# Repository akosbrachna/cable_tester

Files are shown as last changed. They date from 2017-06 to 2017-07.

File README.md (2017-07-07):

# cable_tester

Simple cable tester for checking CAT network cables. It can check wiring issues as well as cable length.

Wiring mismatch testing is based on voltage division.

Cable length measurement is based on signal reflection.

The microcontroller is a PIC18F45k50. This model is used because it has a CTMU unit that enables the 
microcontroller to measure nanosecond short times which is required for cable length measurement. 
The C program was written in MPLAB IDE.

The SMD circuit was designed in Eagle CAD circuit designer. The PCB is double-layered.
Future plan is to add another comparator and make cable length measurement on all 4 pairs.

Master circuit schematic:

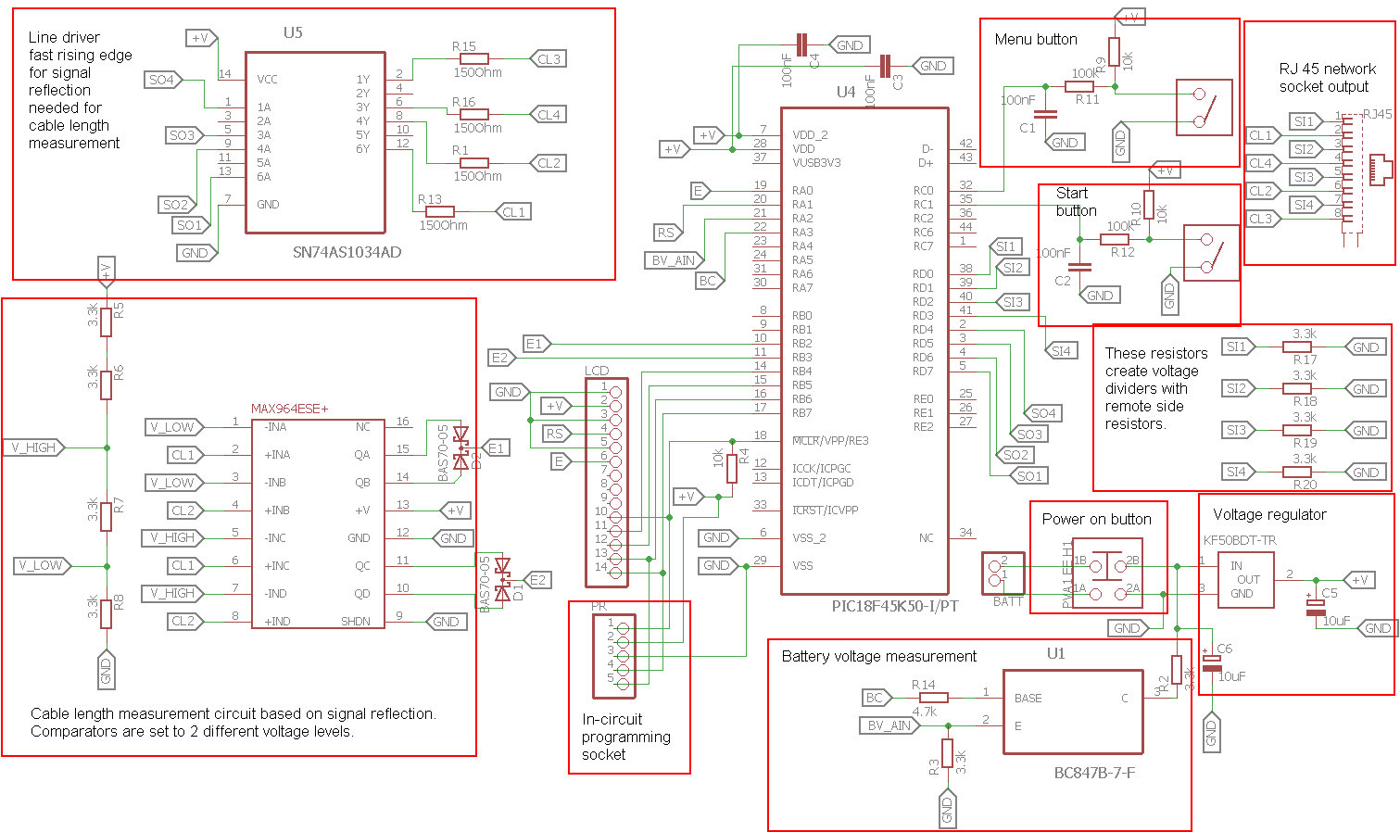
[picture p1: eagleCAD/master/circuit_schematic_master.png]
Circuit schematic


Remote circuit schematic:

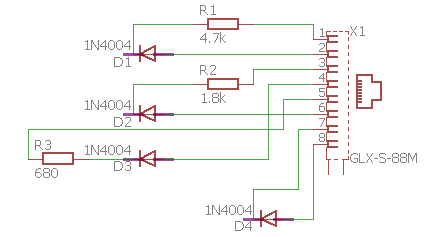
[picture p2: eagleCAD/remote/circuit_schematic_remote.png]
Circuit schematic


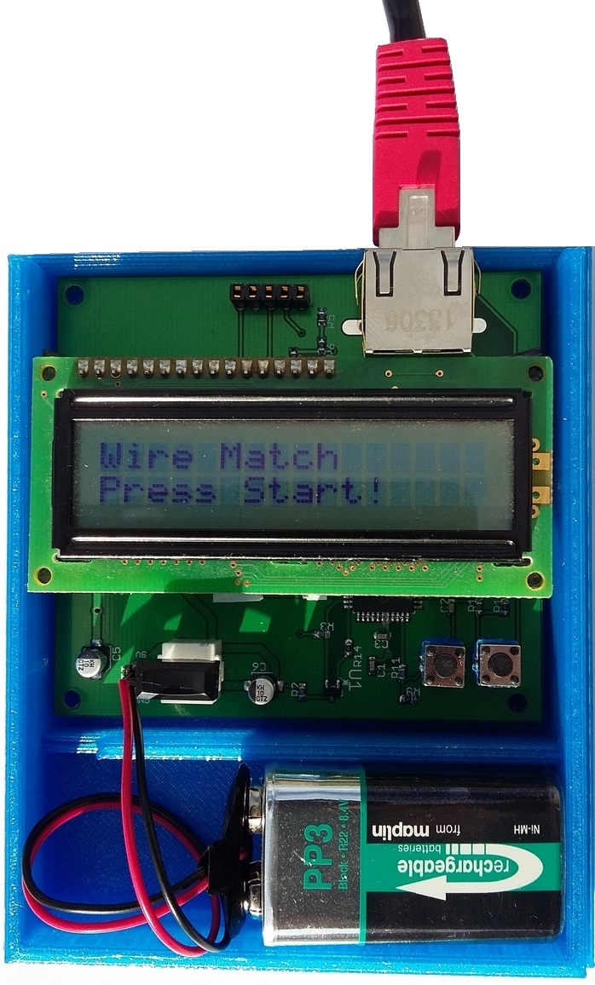
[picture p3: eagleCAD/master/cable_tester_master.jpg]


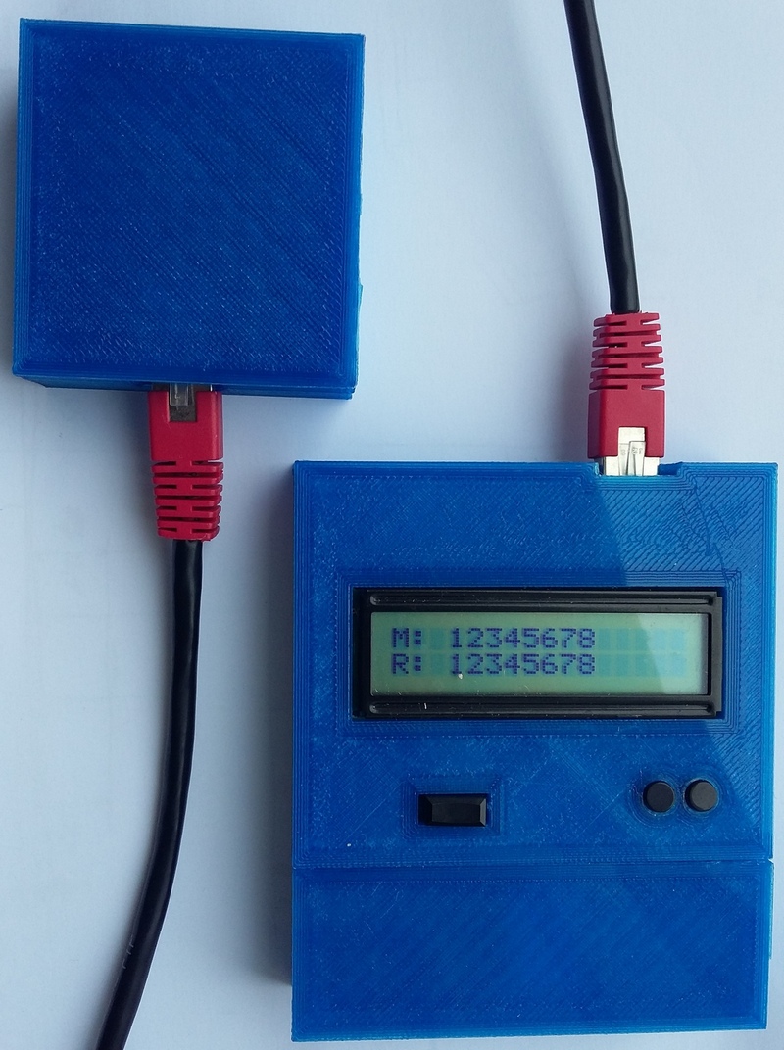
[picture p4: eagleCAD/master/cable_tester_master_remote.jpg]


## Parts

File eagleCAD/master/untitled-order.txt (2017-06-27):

Order list for C:/Users/Setup/Documents/eagle/cable_tester_rx_mod/untitled.sch
Exported from EAGLE with DesignLink

Quantity	Value	Package	Order code	Manufacturer	Manuf. Code	Availability	Price (from)	Description
1		1X02	unknown					
4	100nF	C0603	432210	YAGEO (PHYCOMP)	CC0603KRX7R7BB104	139457	0.0080	YAGEO (PHYCOMP) - CC0603KRX7R7BB104 - CAP, MLCC, X7R, 100NF, 16V, 0603
2	10uF	153CLV-0405	2346364	RUBYCON	16TZV10M4X6.1	972	0.0821	RUBYCON - 16TZV10M4X6.1 - CAP, ALU ELEC, 10UF, 16V, SMD
2	BAS70-05	SOT23	2463435	ON SEMICONDUCTOR	BAV74LT1G	12326	0.026	ON SEMICONDUCTOR - BAV74LT1G - DIODE, SWITCHING, 50V, SOT-23
1		1X14	unknown					
1		1X05	unknown					
4	150Ohm	R0603	1527376	TE CONNECTIVITY / NEOHM	CPF0603F150RC1	551	0.0213	TE CONNECTIVITY / NEOHM - CPF0603F150RC1 - RES, THIN FILM, 150R, 1%, 0.063W, 0603
10	3.3k	R0603	2332009	TE CONNECTIVITY	CRGH0603F3K3	6429	0.0106	TE CONNECTIVITY - CRGH0603F3K3 - RES, THICK FILM, 3K3, 1%, 0.2W, 0603
3	10k	R0603	1652827	VISHAY	CRCW060310K0FKTA	144	0.0158	VISHAY - CRCW060310K0FKTA - RES, THICK FILM, 10K, 1%, 0.1W, 0603
2	100k	R0603	2331753	TE CONNECTIVITY	CRGH0603J100K	7643	0.0084	TE CONNECTIVITY - CRGH0603J100K - RES, THICK FILM, 100K, 5%, 0.2W, 0603
1	4.7k	R0603	1469807	VISHAY	CRCW06034K70FKEA	-2	0.0052	VISHAY - CRCW06034K70FKEA - RES, THICK FILM, 4K7, 1%, 0.1W, 0603
1	1-406541-6	RJ45	2310179	AMP - TE CONNECTIVITY	1-406541-6	2278	1.5	AMP - TE CONNECTIVITY - 1-406541-6 - MODULAR, JACK, RJ45, THT, 8P8C
1		TO252	1467757	STMICROELECTRONICS	KF50BDT-TR	530	0.363	STMICROELECTRONICS - KF50BDT-TR - IC, V REG, LDO 5V, SMD
1	MAX964ESE+	SO16	2518928	MAXIM INTEGRATED PRODUCTS	MAX964ESE+	11	9.74	MAXIM INTEGRATED PRODUCTS - MAX964ESE+ - IC, COMPARATOR, HIGH SPEED,  QUAD
1	PVA1_EE_H1	PVA1_EE_H1	2435325	C & K COMPONENTS	PVA1 EE H1 3.5N V2	1899	0.753	C & K COMPONENTS - PVA1 EE H1 3.5N V2 - SWITCH PUSH DPST
2	FSM4JRT	FSM4JRT	2396052	TE CONNECTIVITY / ALCOSWITCH	FSM4JRT	12410	0.0617	TE CONNECTIVITY / ALCOSWITCH - FSM4JRT - SWITCH, TACTILE, 50MA, 24VDC, THT
1	BC847B-7-F	SOT95P240X110-3N	1773608	DIODES INC.	BC847B-7-F	-2	0.014	DIODES INC. - BC847B-7-F - TRANSISTOR, NPN, SOT23
1	PIC18F45K50-I/PT	TQFP80P1200X1200X120-44N	2305837	MICROCHIP	PIC18F45K50-I/PT	720	2.13	MICROCHIP - PIC18F45K50-I/PT - MCU, 8BIT, PIC18, 48MHZ, TQFP-44
1	SN74AS1034AD	SOIC127P600X175-14N	1470728	TEXAS INSTRUMENTS	SN74AS1034AD	87	1.26	TEXAS INSTRUMENTS - SN74AS1034AD - IC, BUFFER/DRIVER/RECEIVER, SMD

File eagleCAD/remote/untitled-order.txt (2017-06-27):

Order list for C:/Users/Setup/Documents/eagle/cable_tester_remote/untitled.sch
Exported from EAGLE with DesignLink

Quantity	Value	Package	Order code	Manufacturer	Manuf. Code	Availability	Price (from)	Description
4	1N4004	DO41-10	2335181	VISHAY	1N4004-E3/54	23574	0.0307	VISHAY - 1N4004-E3/54 - RECTIFIER, STANDARD, 1A, 400V, DO-204AL
1	4.7k	0309/12	1126988	MULTICOMP	MCMF0W4FF4701A50	856	0.0284	MULTICOMP - MCMF0W4FF4701A50 - METAL FILM RESISTOR, 4.7KOHM, 250mW, 1%
1	1.8k	0309/12	1129139	MULTICOMP	MCMF0W4FF1801A50	3541	0.0284	MULTICOMP - MCMF0W4FF1801A50 - METAL FILM RESISTOR, 1.8KOHM, 250mW, 1%
1	680	0309/12	9340823	MULTICOMP	MF50 680R	13028	0.0158	MULTICOMP - MF50 680R - RESISTOR, 0.5W 1% 680R
1	GLX-S-88M	GLX-S-88M	unknown

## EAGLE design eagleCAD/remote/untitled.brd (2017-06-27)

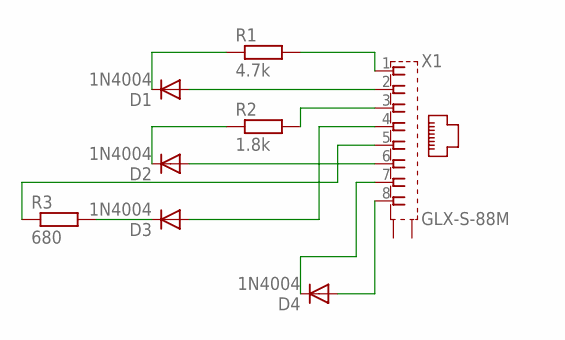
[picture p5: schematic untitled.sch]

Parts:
D1, D2, D3, D4: 1N4004; DO41-10; MPN 1N4004-E3/54
R1: 4.7k; 0309/12; MPN MCMF0W4FF4701A50
R2: 1.8k; 0309/12; MPN MCMF0W4FF1801A50
R3: 680; 0309/12; MPN MF50 680R
X1: GLX-S-88M

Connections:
unnamed: D1.A, X1.2
unnamed: D1.C, R1.1
unnamed: R1.2, X1.1
unnamed: D2.A, X1.6
unnamed: D2.C, R2.1
unnamed: R2.2, X1.3
unnamed: D3.A, X1.4
unnamed: D3.C, R3.2
unnamed: R3.1, X1.5
unnamed: D4.A, X1.8
unnamed: D4.C, X1.7

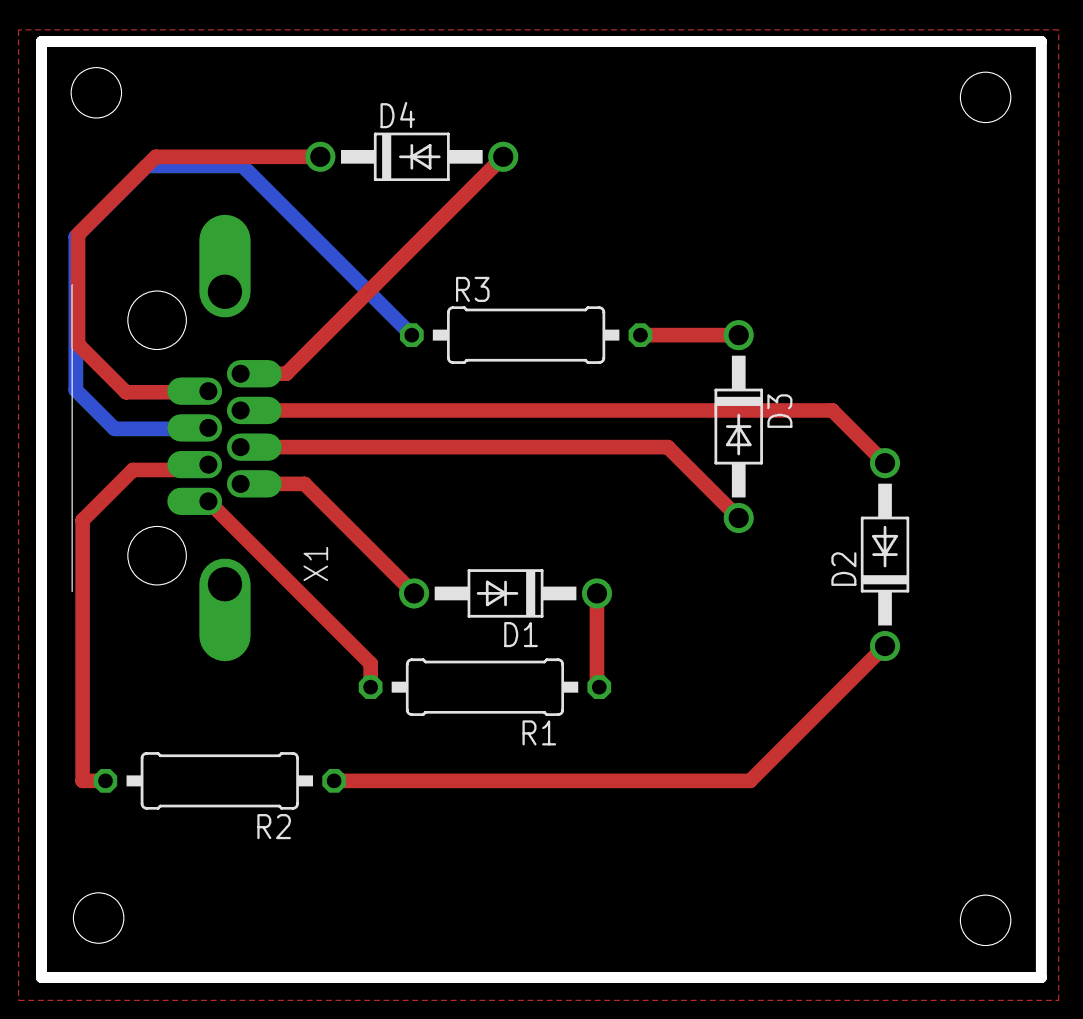
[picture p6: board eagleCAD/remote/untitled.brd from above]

Board: 2 copper layers, 55.5 x 52.0 mm, 8 parts (0 on the bottom side), 11 nets.

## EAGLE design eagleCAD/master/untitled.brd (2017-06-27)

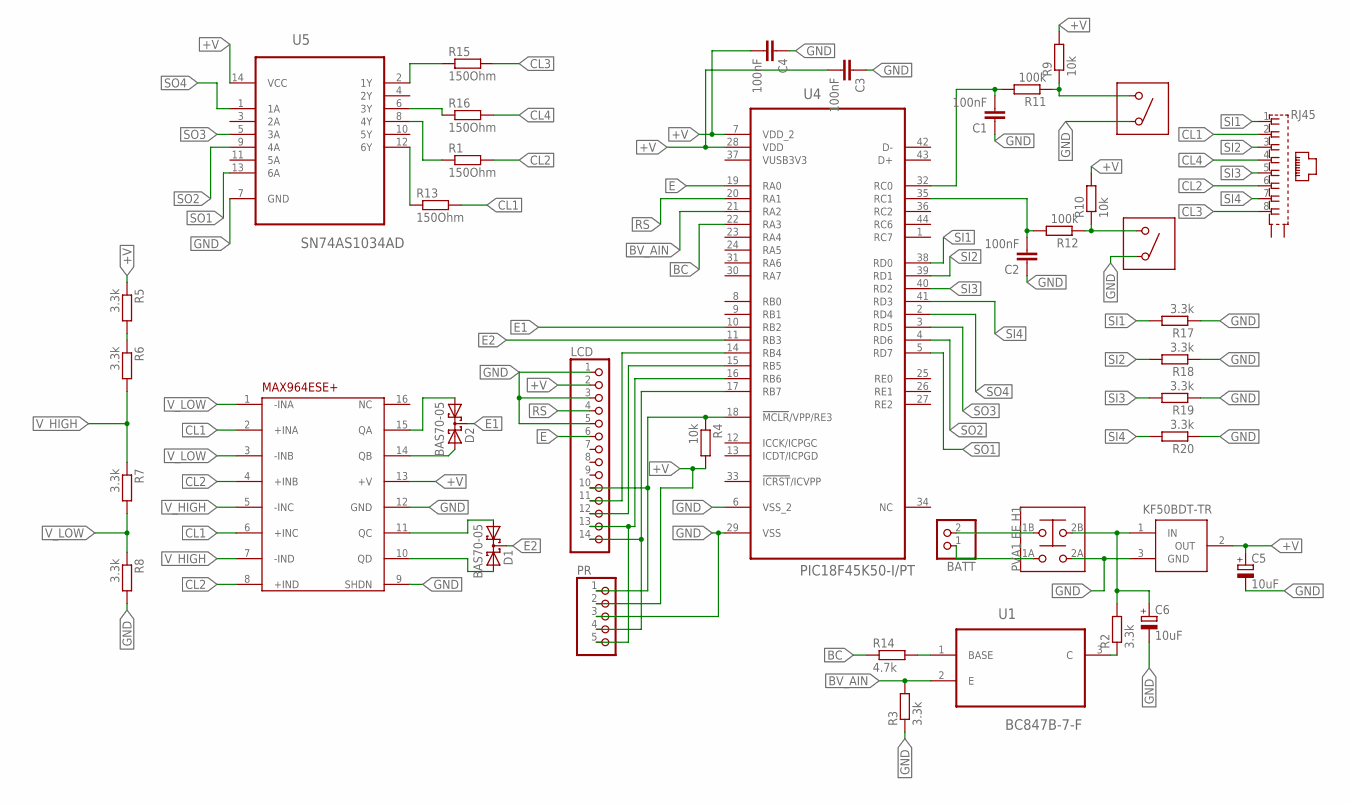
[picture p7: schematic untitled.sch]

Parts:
BATT: PINHD-1X2; 1X02
C1, C2, C3, C4: 100nF; C0603; MPN CC0603KRX7R7BB104
C5, C6: 10uF; 153CLV-0405; MPN 16TZV10M4X6.1
D1, D2: BAS70-05; SOT23
LCD: PINHD-1X14; 1X14
PR: PINHD-1X5; 1X05
R1, R13, R15, R16: 150Ohm; R0603; MPN CPF0603F150RC1
R2, R3, R5, R6, R7, R8, R17, R18, R19, R20: 3.3k; R0603; MPN CRGH0603F3K3
R4, R9, R10: 10k; R0603; MPN CRCW060310K0FKTA
R11, R12: 100k; R0603; MPN CRGH0603J100K
R14: 4.7k; R0603; MPN CRCW06034K70FKEA
RJ45: 1-406541-6; RJ45
U1: BC847B-7-F; SOT95P240X110-3N
U4: PIC18F45K50-I/PT; TQFP80P1200X1200X120-44N
U5: SN74AS1034AD; SOIC127P600X175-14N
U$1: KF50BDT-TR; TO252
U$2: MAX964ESE+; SO16; MPN MAX964ESE+
U$3: PVA1_EE_H1
U$4, U$5: FSM4JRT; MPN FSM4JRT

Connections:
+V: C3.2, C4.2, C5.+, LCD.2, PR.2, R4.2, R5.1, R9.2, R10.2, U4.7 (VDD_2), U4.28 (VDD), U5.14 (VCC), U$1.2 (OUT), U$2.13 (+V)
BC: R14.1, U4.22 (RA3)
BV_AIN: R3.2, U1.2 (E), U4.21 (RA2)
CL1: R13.2, RJ45.2, U$2.2 (+INA), U$2.6 (+INC)
CL2: R1.2, RJ45.6, U$2.4 (+INB), U$2.8 (+IND)
CL3: R15.2, RJ45.8
CL4: R16.2, RJ45.4
E: LCD.6, U4.19 (RA0)
E1: D2.3 (C), U4.10 (RB2)
E2: D1.3 (C), U4.11 (RB3)
GND: C1.1, C2.1, C3.1, C4.1, C5.-, C6.-, LCD.1, LCD.3, LCD.5, PR.3, R3.1, R8.2, R17.1, R18.1, R19.1, R20.1, U4.6 (VSS_2), U4.29 (VSS), U5.7 (GND), U$1.3 (GND), U$2.9 (SHDN), U$2.12 (GND), U$3.2A, U$4.2, U$5.2
MCLR: LCD.10, PR.1, R4.1, U4.18 (!MCLR!/VPP/RE3)
unnamed: LCD.11, U4.14 (RB4)
unnamed: LCD.12, U4.15 (RB5)
unnamed: R14.2, U1.1 (BASE)
unnamed: R2.1, U1.3 (C)
unnamed: R1.1, U5.8 (4Y)
unnamed: R13.1, U5.12 (6Y)
unnamed: R16.1, U5.6 (3Y)
unnamed: LCD.13, PR.5, U4.16 (RB6)
unnamed: C1.2, R11.2, U4.32 (RC0)
unnamed: BATT.2, U$3.1B
unnamed: R15.1, U5.2 (1Y)
unnamed: BATT.1, U$3.1A
unnamed: LCD.14, PR.4, U4.17 (RB7)
unnamed: D2.1 (A1), U$2.15 (QA)
unnamed: R5.2, R6.1
unnamed: D2.2 (A2), U$2.14 (QB)
unnamed: D1.1 (A1), U$2.11 (QC)
unnamed: R9.1, R11.1, U$4.1
unnamed: D1.2 (A2), U$2.10 (QD)
unnamed: C2.2, R12.2, U4.35 (RC1)
unnamed: R10.1, R12.1, U$5.1
unnamed: C6.+, R2.2, U$1.1 (IN), U$3.2B
RS: LCD.4, U4.20 (RA1)
SI1: R17.2, RJ45.1, U4.38 (RD0)
SI2: R18.2, RJ45.3, U4.39 (RD1)
SI3: R19.2, RJ45.5, U4.40 (RD2)
SI4: R20.2, RJ45.7, U4.41 (RD3)
SO1: U4.5 (RD7), U5.13 (6A)
SO2: U4.4 (RD6), U5.9 (4A)
SO3: U4.3 (RD5), U5.5 (3A)
SO4: U4.2 (RD4), U5.1 (1A)
VUSB3V3: U4.37 (VUSB3V3)
V_HIGH: R6.2, R7.1, U$2.5 (-INC), U$2.7 (-IND)
V_LOW: R7.2, R8.1, U$2.1 (-INA), U$2.3 (-INB)

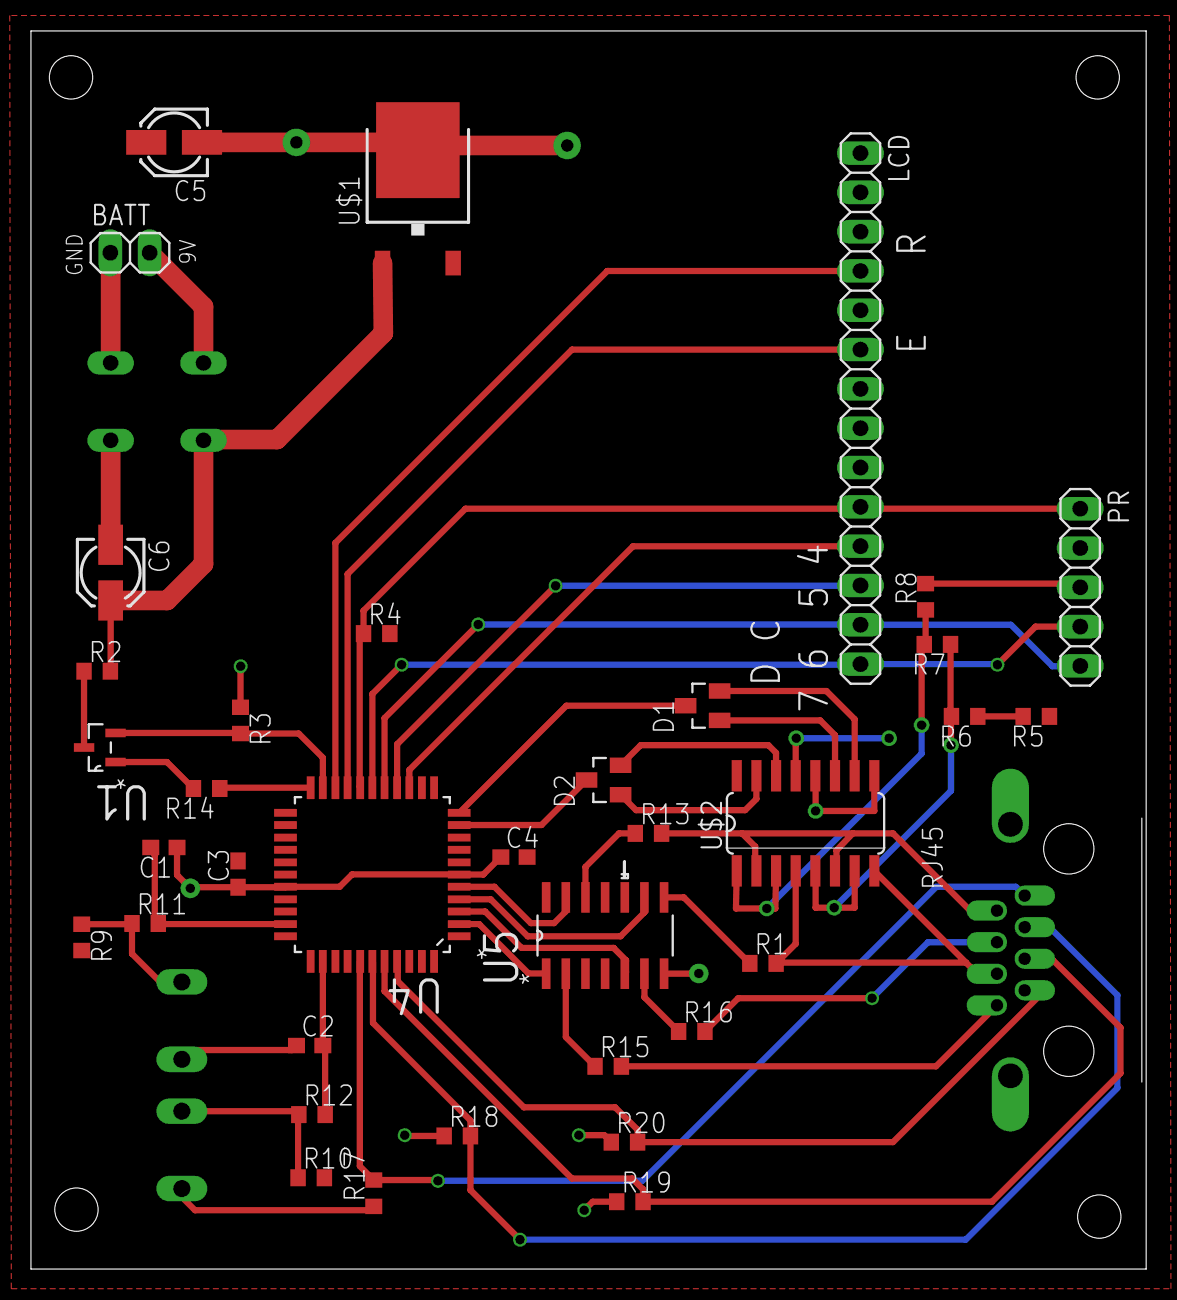
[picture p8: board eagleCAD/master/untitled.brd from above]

Board: 2 copper layers, 72.1 x 80.0 mm, 40 parts (0 on the bottom side), 45 nets.

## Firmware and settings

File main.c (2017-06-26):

#define elemszam(x) (sizeof(x)/sizeof(x[0]))
#define abs(x) ((x) > 0 ? (x) : -(x))
#include <p18f45k50.h>
#include <delays.h>
#include <stdlib.h>
#include "eeprom.h"
#include "config_45k50.h"
#include "lcd.h"
#include "menu.h"
#include "std_lib.h"
#include "sort.h"
#include "wire_match.h"
#include "wire_match_calibration.h"
#include "cable_length.h"

void init(void);

unsigned char buf[8];

void main(void)
{
	init();

	while(1)
	{
		Delay10KTCYx(50);

		while (PORTCbits.RC0 == 1)
		{	
			menu(); 
		}

		Lcd_clearDisplay();
		Lcd_cursorHome();

		switch(check_switch)
		{
			case 0:
			{
				Lcd_PutMessage("Testing");
				check_wire_match();
				break;
			}
			case 1:
			{
				//Lcd_PutMessage("Orange: ");
				measure_cable_length(0b10000000);
				//Lcd_cursorHome();Lcd_newLine();
				//Lcd_PutMessage("Green: ");
				//measure_cable_length(0b10110000);
				break;
			}
			case 2:
			{
				calibrate_length();
				break;
			}
			case 3:
			{
				calibrate_wire_match();
				break;
			}
		}
	}
}

void init(void)
{
	OSCCON = 0b01010110; //4MHz orajel T = 250ns, 1 utasitas = 1us	
	TRISA  = 0b00000100;
	TRISB  = 0b00001100;
	TRISC  = 0b00000011;
	TRISD  = 0b00001111;
	LATA = 0;
	LATD = 0;
	LATD = 0b00000000;
	ANSELA = 0;
	ANSELB = 0;
	ANSELC = 0;
	ANSELD = 0;

	CM1CON0 = 0;
	CM2CON0 = 0;

	ADCON1 = 0;				//VSS,VDD ref.
	//ADCON2 = 0b00010001;;	//ADCON2 setup: Left justified, Tacq=4Tad, Tad=Fosc/8)
	ADCON2 = 0b00101111;	//ADCON2 setup: Left justified, Tacq=12Tad, Tad=FRC)

	CTMUCONH = 0x00; //make sure CTMU is disabled
	CTMUCONL = 0b11011100;
	CTMUICON = 0b01111111; //55uA, Nominal - Max positive Adjustment

	Lcd_init();

	measure_battery();
	//EEPROM_reset(50);
	copy_eeprom_to_buffer(); //copy calibrated length data to buffer
	copy_eeprom_wire_match_to_buffer();
	display_main_menu();
}

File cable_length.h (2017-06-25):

unsigned int ethernet_cable_length[]={500, 1000, 2500, 5000, 7500, 10000};
unsigned int ethernet_cable_ADC[6];
unsigned char calibration_check_switch;
const unsigned char calibration_last_menu = 7;
const unsigned char calibration_reset_menu = 6;
unsigned char calibration_down_up;

void copy_eeprom_to_buffer(void)
{
unsigned char i;
unsigned char check[2];

	check[0] = EEPROM_getc(0xFE);
	check[1] = EEPROM_getc(0xFF);
	if (check[0] == 0x55 && check[1] == 0xAA)
	{
		for(i = 0; i < elemszam(ethernet_cable_ADC); i++)
		{
			ethernet_cable_ADC[i] = EEPROM_get_int(i*2);
		}
	}
	else
	{
		for(i = 0; i < elemszam(ethernet_cable_ADC); i++)
		{
			ethernet_cable_ADC[i] = 0;
			EEPROM_put_int(i*2, 0);
		}
		EEPROM_putc(0xFE, 0x55);
		EEPROM_putc(0xFF, 0xAA);
	}

}

unsigned int adc_to_length(unsigned int data)
{
float factory_length = 12.20476;
float adat;
unsigned char i;
unsigned char min_index = 100;
unsigned int min = 10000;

	for (i = 0; i < elemszam(ethernet_cable_ADC); i++)
	{
		if (ethernet_cable_ADC[i] == 0) continue;
		if (min > abs(data - ethernet_cable_ADC[i]))
		{
			min = abs(data - ethernet_cable_ADC[i]);
			min_index = i;
		}
	}
	if (min_index != 100)
	{
		adat = data*((float)ethernet_cable_length[min_index]/(float)ethernet_cable_ADC[min_index]);
	}
	else{
		adat = data*factory_length;
	}
	return (int)adat;
}

void measure_cable_length(unsigned char channel)
{
	unsigned char i = 0;
	unsigned int data[10];
	unsigned int value;
	unsigned char minmax_index[2];
	unsigned char buf[8];
	unsigned char tris_d;

	tris_d = TRISD;
	TRISD = 0b00000000;

	ADCON0 = 0b01110101;
	CTMUCONHbits.CTMUEN = 1; 		//Enable the CTMU

	Delay10TCYx(50);

	while(i < elemszam(data))
	{	
		CTMUCONLbits.EDG1STAT = 0; 	//Set Edge status bits to zero
		CTMUCONLbits.EDG2STAT = 0;
		CTMUCONHbits.IDISSEN = 1; 	//drain charge on the circuit
		Delay10TCYx(100); 			//wait for 1ms 4Mhz clock
		CTMUCONHbits.IDISSEN = 0; 	//end drain of circuit
	
		CTMUCONHbits.EDGEN = 1;
		LATD = channel;
		
		while(CTMUCONLbits.EDG2STAT == 0);
		data[i] = adc_conv();
		LATD = 0b00000000;
		Delay1KTCYx(50);			//50ms
		i++;
	}
	CTMUCONHbits.CTMUEN = 0; 		//Disable the CTMU
	TRISD = tris_d;
	LATD = 0b00000000;

	sort(data, elemszam(data));
	stat(data, elemszam(data), minmax_index);
	value = average(data, minmax_index);
	value = adc_to_length(value);
	if ((minmax_index[1]-minmax_index[0])<5)
	{
		Lcd_clearDisplay();Lcd_cursorHome();
		Lcd_PutMessage("Erronous");
		//Lcd_cursorHome();Lcd_newLine();
		//Lcd_PutMessage("Please try again");
		return;
	}
	if (float_to_string(value, buf, 'm'))
		Lcd_PutMessageArray(buf);
	else {
		Lcd_clearDisplay();
		Lcd_PutMessage("Error");
		//Lcd_cursorHome();Lcd_newLine();
		//Lcd_PutMessage("Please try again");
	}

	Delay10KTCYx(5);
}

void display_calibration_menu(void)
{
const char *length_values[] = {"5 meters", "10 meters", "25 meters", "50 meters", "75 meters", "100 meters", "reset", "exit"};
	Lcd_clearDisplay();
	Lcd_cursorHome();
	Lcd_PutMessage("Choose length: ");
	Lcd_cursorHome();Lcd_newLine();
	if (ethernet_cable_ADC[calibration_check_switch] && calibration_check_switch < calibration_reset_menu)
	{
		Lcd_PutMessage("* ");
	}
	Lcd_PutMessage(length_values[calibration_check_switch]);
}

void calibration_menu(void)
{
	if (PORTCbits.RC1 == 1)
	{
		calibration_down_up = 0;
		return;
	}
	if (calibration_down_up == 1)
		return;

	calibration_down_up = 1;
	if (calibration_check_switch != calibration_last_menu)
		calibration_check_switch++;
	else calibration_check_switch = 0;

	display_calibration_menu();
}

void make_calibration(void)
{
	unsigned char i = 0;
	unsigned int data[10];
	unsigned int value;
	unsigned char minmax_index[2];
	unsigned char buf[8];

	TRISD  = 0b00000000;
	LATD   = 0b00000000;
	ADCON0 = 0b01110101;

	CTMUCONHbits.CTMUEN = 1; 		//Enable the CTMU

	Delay10TCYx(50);

	while(i < elemszam(data))
	{	
		CTMUCONLbits.EDG1STAT = 0; 	//Set Edge status bits to zero
		CTMUCONLbits.EDG2STAT = 0;
		CTMUCONHbits.IDISSEN = 1; 	//drain charge on the circuit
		Delay10TCYx(100); 			//wait for 1ms 4Mhz clock
		CTMUCONHbits.IDISSEN = 0; 	//end drain of circuit
	
		CTMUCONHbits.EDGEN = 1;
		LATDbits.LATD7 = 1;
		
		while(CTMUCONLbits.EDG2STAT == 0);

		data[i] = adc_conv();
		LATDbits.LATD7 = 0;

		Delay1KTCYx(50);			//50ms
		i++;
	}
	LATD  = 0b00000000;
	CTMUCONHbits.CTMUEN = 0; 		//Disable the CTMU

	sort(data, elemszam(data));
	stat(data, elemszam(data), minmax_index);
	value = average(data, minmax_index);
	EEPROM_put_int(calibration_check_switch*2, value);
	ethernet_cable_ADC[calibration_check_switch] = value;

	Delay10KTCYx(5);
}

void calibrate_length(void)
{
	unsigned int value;
	unsigned char i;

	calibration_check_switch = 0;
	calibration_down_up = 0;

	display_calibration_menu();

	while (PORTCbits.RC0 == 0){}

	while (PORTCbits.RC0 == 1)
	{	
		calibration_menu(); 
	}
	if (calibration_check_switch < calibration_reset_menu) 
	{
		make_calibration();
	}
	if (calibration_check_switch == calibration_reset_menu) 
	{
		for(i = 0; i < elemszam(ethernet_cable_ADC); i++)
		{
			ethernet_cable_ADC[i] = 0;
			EEPROM_put_int(i*2, 0);
		}
	}
	display_main_menu();
}
